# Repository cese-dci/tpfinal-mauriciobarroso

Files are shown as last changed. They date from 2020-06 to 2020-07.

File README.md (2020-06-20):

# EEMON - Energy Meter Monitor

El sistema propuesto se encarga de obtener los pulsos ópticos provenientes de un medidor de energía eléctrica docmiciliario, los almacena en una memoria no volátil para procesarlos y enviarlos a un gateway LoRaWAN propiedad de la empresa prestadora del servicio.

También, posee la capacidad de conectarse a una red Wi-Fi o generar una propia y funcionar como servidor web para que el abonado del servicio eléctrico pueda acceder a una interfaz desde donde podrá observar su consumo de energía eléctrica actual y un historial del mismo.

El PCB diseñado tendrá la función de servir como soporte a todos los componentes del sistema que dejarán de ser placas de desarrollo y serán reemplazados por componentes sueltos, también se servirá como soporte para la instalación de conectores apropiados para los módulos de conversión óptico-eléctrico y el programador del microcontrolador.

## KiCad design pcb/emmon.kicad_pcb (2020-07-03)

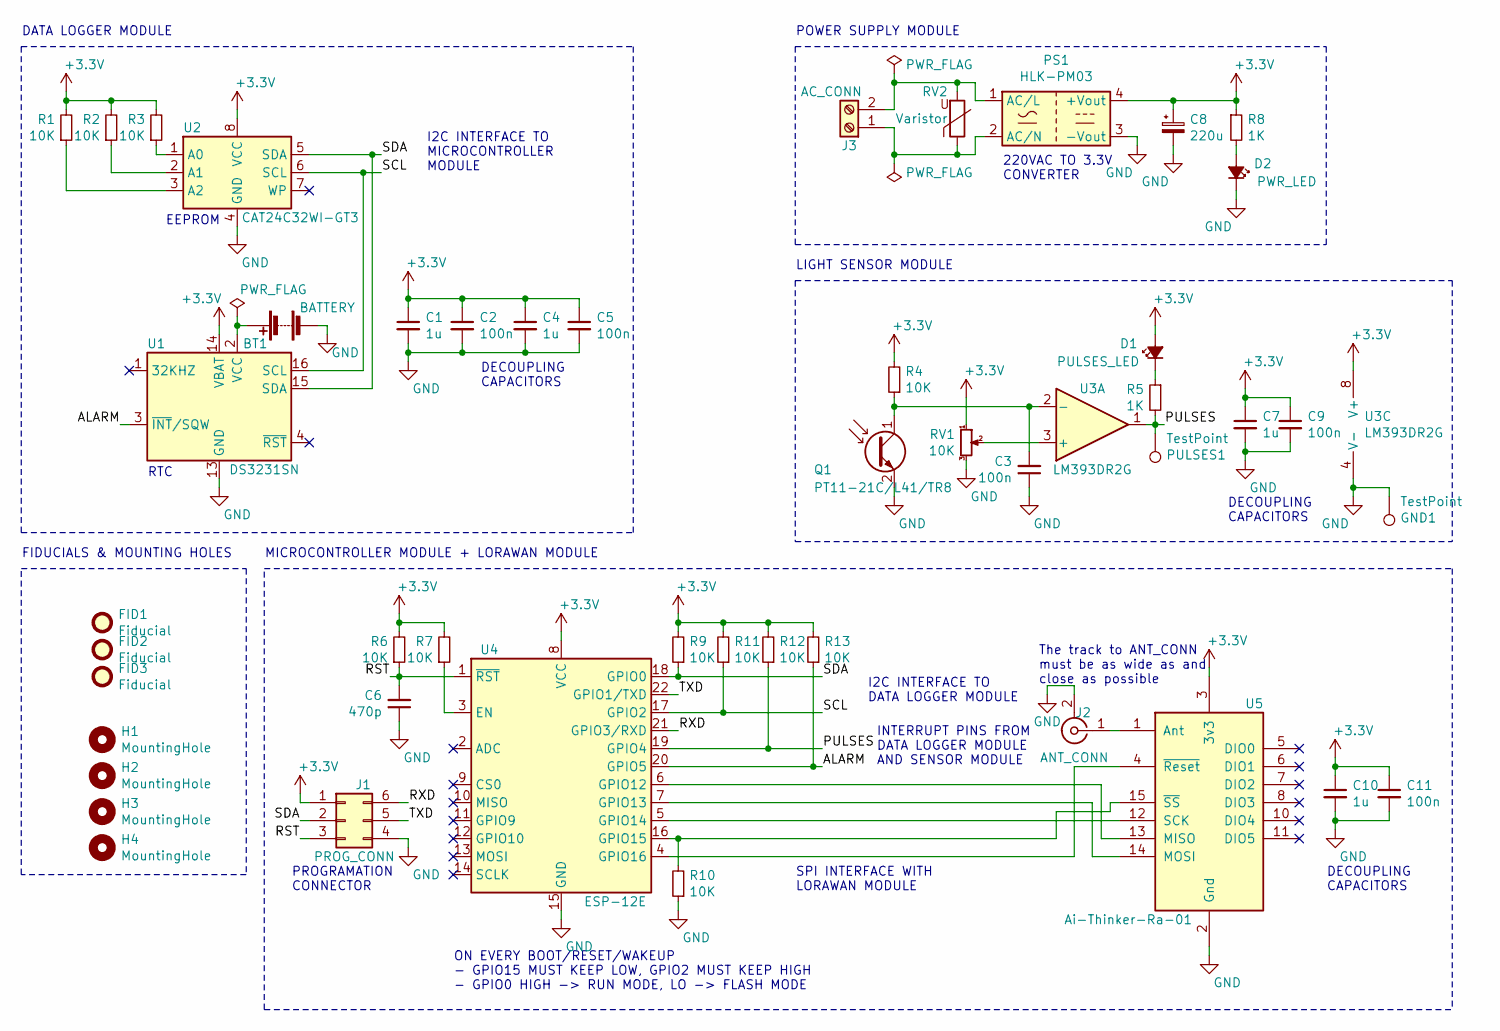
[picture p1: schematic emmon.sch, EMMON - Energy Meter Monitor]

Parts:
BT1: BATTERY; BatteryHolder_Keystone_1060_1x2032; LCSC C70377
C1, C4, C7, C10: 1u; C_0805_2012Metric_Pad1.15x1.40mm_HandSolder; LCSC C28323
C2, C5, C9, C11: 100n; C_0805_2012Metric_Pad1.15x1.40mm_HandSolder; LCSC C49678
C3: 100n; C_0805_2012Metric_Pad1.15x1.40mm_HandSolder
C6: 470p; C_0805_2012Metric_Pad1.15x1.40mm_HandSolder; LCSC C1743
C8: 220u; C_Radial_D6.3mm_H11.0mm_P2.50mm; LCSC C271304
D1: PULSES_LED; LED_D3.0mm
D2: PWR_LED; LED_D3.0mm
FID1, FID2, FID3: Fiducial; Fiducial_1mm_Mask2mm
GND1: TestPoint; TestPoint_THTPad_3.0x3.0mm_Drill1.5mm
H1, H2, H3, H4: MountingHole; MountingHole_2.7mm_M2.5
J1: PROG_CONN; PinHeader_2x03_P2.54mm_Vertical; LCSC C65114
J2: ANT_CONN; SMA_Molex_73251-1153_EdgeMount_Horizontal; LCSC C496550
J3: AC_CONN; TerminalBlock_Phoenix_MKDS-1,5-2-5.08_1x02_P5.08mm_Horizont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; LCSC C89120
PS1: HLK-PM03; Converter_ACDC_HiLink_HLK-PMxx; LCSC C209904
PULSES1: TestPoint; TestPoint_THTPad_3.0x3.0mm_Drill1.5mm
Q1: PT11-21C/L41/TR8; LED_1206_3216Metric_Pad1.42x1.75mm_HandSolder; LCSC C16746
R1, R2, R3, R4, R6, R7, R9, R10, R11, R12, R13: 10K; R_0805_2012Metric_Pad1.15x1.40mm_HandSolder; LCSC C17414
R5, R8: 1K; R_0805_2012Metric_Pad1.15x1.40mm_HandSolder; LCSC C17513
RV1: 10K; Potentiometer_Bourns_3386P_Vertical; LCSC C118953
RV2: Varistor; RV_Disc_D12mm_W3.9mm_P7.5mm; LCSC C233178
U1: DS3231SN; SOIC-16W_7.5x10.3mm_P1.27mm; LCSC C9866
U2: CAT24C32WI-GT3; SOIC-8_3.9x4.9mm_P1.27mm; LCSC C81193
U3: LM393DR2G; SOIC-8_3.9x4.9mm_P1.27mm; LCSC C7955
U4: ESP-12E; LCSC C89297
U5: Ai-Thinker-Ra-01; Ai-Thinker-Ra-01-LoRa; LCSC C90040

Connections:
+3V3: C1.1, C2.1, C4.1, C5.1, C7.1, C8.1, C9.1, C10.1, C11.1, D1.2 (A), J1.1, PS1.4 (+Vout), R1.2, R2.2, R3.2, R4.2, R6.2, R7.2, R8.1, R9.2, R11.2, R12.2, R13.2, RV1.1, U1.14 (VBAT), U2.8 (VCC), U3.8 (V+), U4.8 (VCC), U5.3 (3v3)
/ALARM: R13.1, U1.3 (~INT~/SQW), U4.20 (GPIO5)
/PULSES: PULSES1.1, R5.2, R12.1, U3.1, U4.19 (GPIO4)
/RST: C6.2, J1.3, R6.1, U4.1 (~RST)
/RXD: J1.6, U4.21 (GPIO3/RXD)
/SCL: R11.1, U1.16 (SCL), U2.6 (SCL), U4.17 (GPIO2)
/SDA: J1.2, R9.1, U1.15 (SDA), U2.5 (SDA), U4.18 (GPIO0)
/TXD: J1.5, U4.22 (GPIO1/TXD)
GND: BT1.2 (-), C1.2, C2.2, C3.1, C4.2, C5.2, C6.1, C7.2, C8.2, C9.2, C10.2, C11.2, D2.1 (K), GND1.1, J1.4, J2.2 (Ext), PS1.3 (-Vout), Q1.2 (E), R10.1, RV1.3, U1.5 (GND), U1.6 (GND), U1.7 (GND), U1.8 (GND), U1.9 (GND), U1.10 (GND), U1.11 (GND), U1.12 (GND), U1.13 (GND), U2.4 (GND), U3.4 (V-), U4.15 (GND), U5.2 (Gnd), U5.9 (Gnd), U5.16 (Gnd)
unnamed: BT1.1 (+), U1.2 (VCC)
unnamed: C3.2, Q1.1 (C), R4.1, U3.2 (-)
unnamed: D1.1 (K), R5.1
unnamed: D2.2 (A), R8.2
unnamed: J2.1 (In), U5.1 (Ant)
unnamed: J3.1, PS1.2 (AC/N), RV2.1
unnamed: J3.2, PS1.1 (AC/L), RV2.2
unnamed: R1.1, U2.3 (A2)
unnamed: R2.1, U2.2 (A1)
unnamed: R3.1, U2.1 (A0)
unnamed: R7.1, U4.3 (EN)
unnamed: R10.2, U4.16 (GPIO15), U5.15 (~SS)
unnamed: RV1.2, U3.3 (+)
unnamed: U4.4 (GPIO16), U5.4 (~Reset)
unnamed: U4.5 (GPIO14), U5.12 (SCK)
unnamed: U4.6 (GPIO12), U5.13 (MISO)
unnamed: U4.7 (GPIO13), U5.14 (MOSI)

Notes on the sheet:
LIGHT SENSOR MODULE
DECOUPLING CAPACITORS
EEPROM
RTC
DATA LOGGER MODULE
FIDUCIALS & MOUNTING HOLES
POWER SUPPLY MODULE
I2C INTERFACE TO MICROCONTROLLER MODULE
I2C INTERFACE TO DATA LOGGER MODULE
INTERRUPT PINS FROM DATA LOGGER MODULE AND SENSOR MODULE
220VAC TO 3.3V CONVERTER
MICROCONTROLLER MODULE + LORAWAN MODULE
SPI INTERFACE WITH LORAWAN MODULE
ON EVERY BOOT/RESET/WAKEUP - GPIO15 MUST KEEP LOW, GPIO2 MUST KEEP HIGH - GPIO0 HIGH -> RUN MODE, LO -> FLASH MODE
PROGRAMATION CONNECTOR
The track to ANT_CONN must be as wide as and close as possible

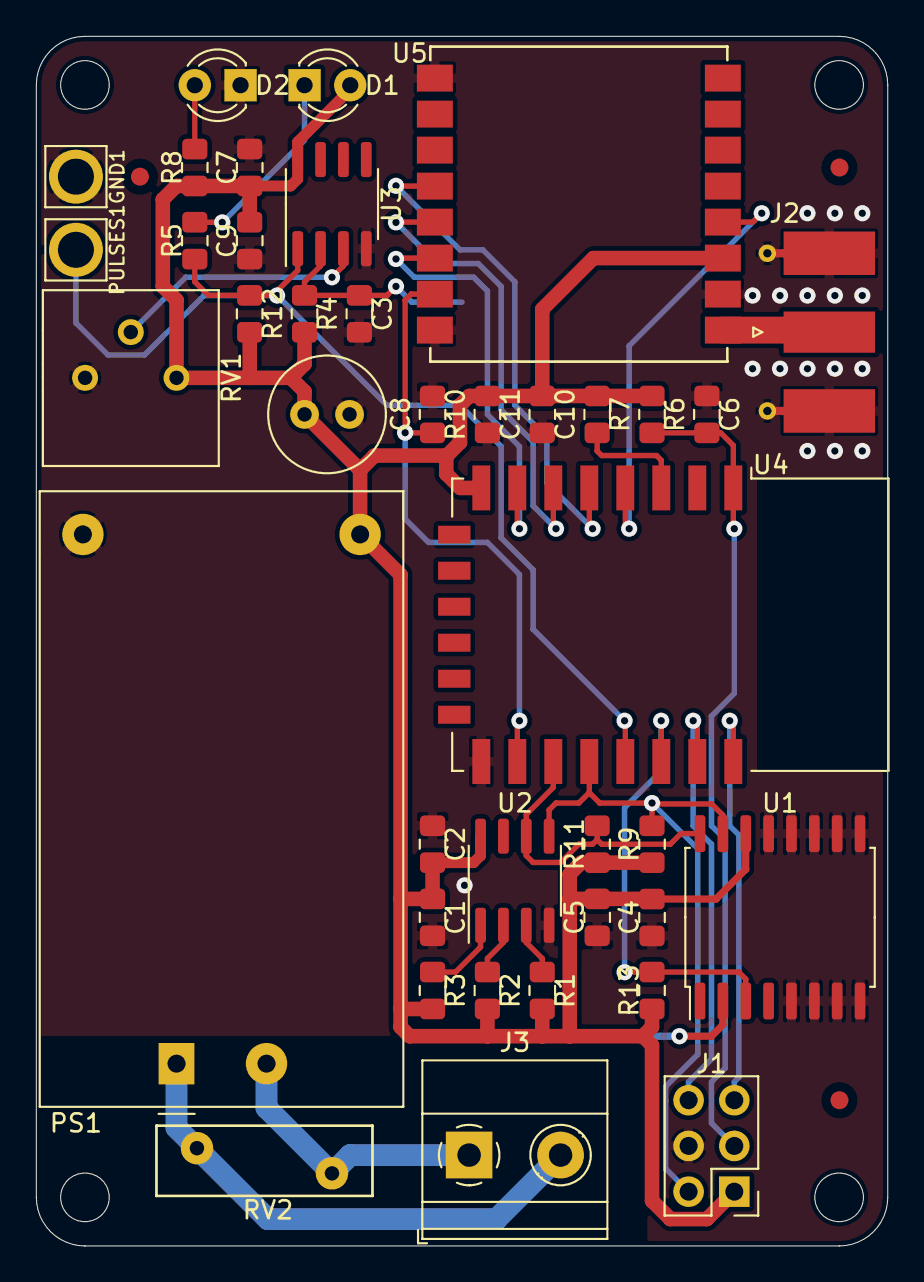
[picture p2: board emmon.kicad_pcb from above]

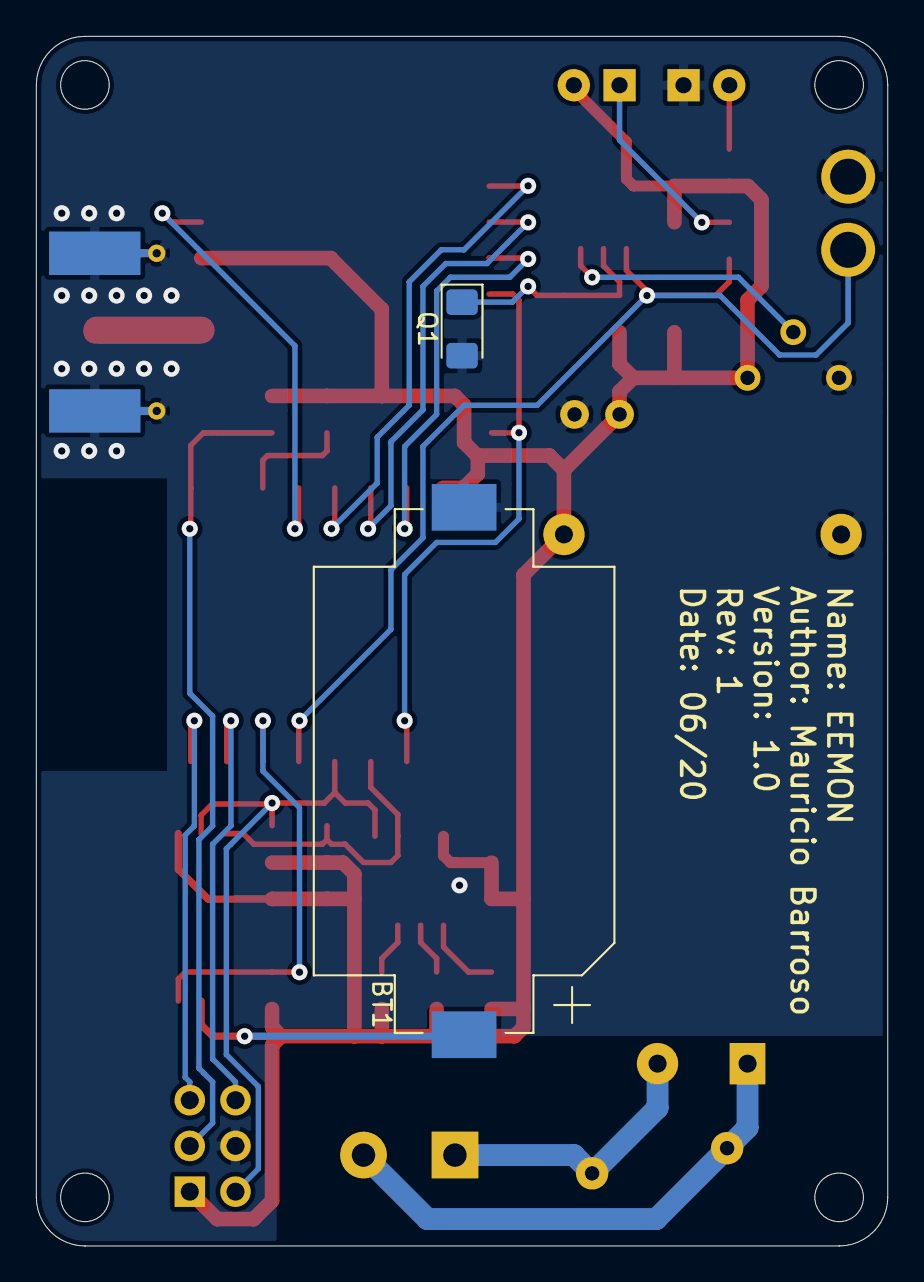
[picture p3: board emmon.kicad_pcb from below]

Board: 2 copper layers, 47.3 x 67.2 mm, 48 parts (2 on the bottom side), 26 nets.

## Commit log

2020-05-09 se agregan datasheets y el proyecto de kicad
    [emmon.kicad_pcb, emmon.sch]
2020-05-17 se avanza en el ruteo de pistas
    [emmon.kicad_pcb, emmon.sch]
2020-06-06 se completa el esquemático y se avanza en el posicionamiento del pcb
    [emmon-B_Cu.gbl, emmon-B_Mask.gbs, emmon-B_SilkS.gbo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]
2020-06-06 se elimina carpeta gerber
    [emmon-B_Cu.gbl, emmon-B_Mask.gbs, emmon-B_SilkS.gbo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]
2020-06-06 se eliminan archivos temporales
    [emmon.kicad_pcb]
2020-06-06 se eliminan archivos temporales y de backup
    [emmon-Edge_Cuts.gm1]
2020-06-06 se agrega modelo 3D para RA-01
    [emmon.kicad_pcb]
2020-06-12 se edita el esquemático y se añade el pcb
    [emmon.kicad_pcb, emmon.sch]
2020-06-12 se cambia la ubicación de los modelos 3d
    [emmon.kicad_pcb]
2020-06-12 se modifican los anchos de pista del pcb
    [emmon.kicad_pcb]
2020-06-19 Se corrigen las observaciones del docente
    [emmon.kicad_pcb, emmon.sch]
2020-06-19 se agregan datasheets de los componentes principales
2020-06-19 se agrega texto informativo en la sergrafía
    [emmon.kicad_pcb]
2020-06-19 se cambia la ruta de los componentes 3D
    [emmon.kicad_pcb]
2020-06-20 se ejecuta el DRC cambiando el ancho de pista
    [emmon.kicad_pcb]
2020-06-20 se cambia la posición de los capacitores de bypass de U5
    [emmon.kicad_pcb]
2020-06-20 se agrega licencia
    [emmon.kicad_pcb, emmon.sch]
2020-06-20 se corrige linea de AC
    [emmon.kicad_pcb]
2020-07-03 se aplican las correciones de la revisión del profesor
    [emmon.kicad_pcb, emmon.sch]

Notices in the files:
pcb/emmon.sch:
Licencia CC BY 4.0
